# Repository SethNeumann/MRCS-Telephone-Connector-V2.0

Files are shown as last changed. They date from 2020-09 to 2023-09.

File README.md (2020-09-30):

# REPO NAME: MRCS0Telephone-Connector-V2.0
## License: Creative Commons Attribution-NonCommercial-ShareAlike

This board provides connectors to extend the MRCS power and phone bus (used by the EBF31A Battery Feed and ATSN Dispatcher/Operator Boards) to as many as 12 stations. Pads are provided for a bucking converter to develop 12VDC for buzzers, LEDs and Relay Latches. I’ve been developing a series of circuit boards to perform the various functions needed to build a layout phone system, but I never made a central board to distribute the phone line and auxiliary power. In the past I assumed the user would use either telephone style “66 blocks” or barrier strips to distribute these signals, but that has become a road block for some users, so this board, with its on board screw terminals puts the basic connections in one place. Features:

• Takes power from the 6-conductor modular telephone and +24V power bus (note to phone people: this is positive 24 to keep things simple for non-phone model railroaders) • Two 6 conductor Jacks are provided for daisy chaining the bus. Connectors are oriented with the locking tab up for easy connection and disconnection.

• Connector pads provide up to 12 connections on 0.100 centers for Tip, Ring, +12 and Ground. If you are assembling your own board and need less connections, you can use screw terminals (or your favorite 0.100 connector) with fewer positions

• Optional auxiliary 6 position screw terminal brings all lines on the bus out for easy access

• Polarity protection diode protects against use of non-reversing (DCC Bus 6 conductor cable)

- 2.1 mm barrel jack for 24vdc input

• Pads for an LM2596 bucking converter which provides 12V for buzzers, LEDs and Relay Latches etc., or you can substitute a boost converter for any voltage up to 35VDC

All components are through-hole technology for ease of assembly and repair.

You are free to download these files and make your own boards or cou can purchase bare boards or assembled and tested product from Model Railroad Control Systems.

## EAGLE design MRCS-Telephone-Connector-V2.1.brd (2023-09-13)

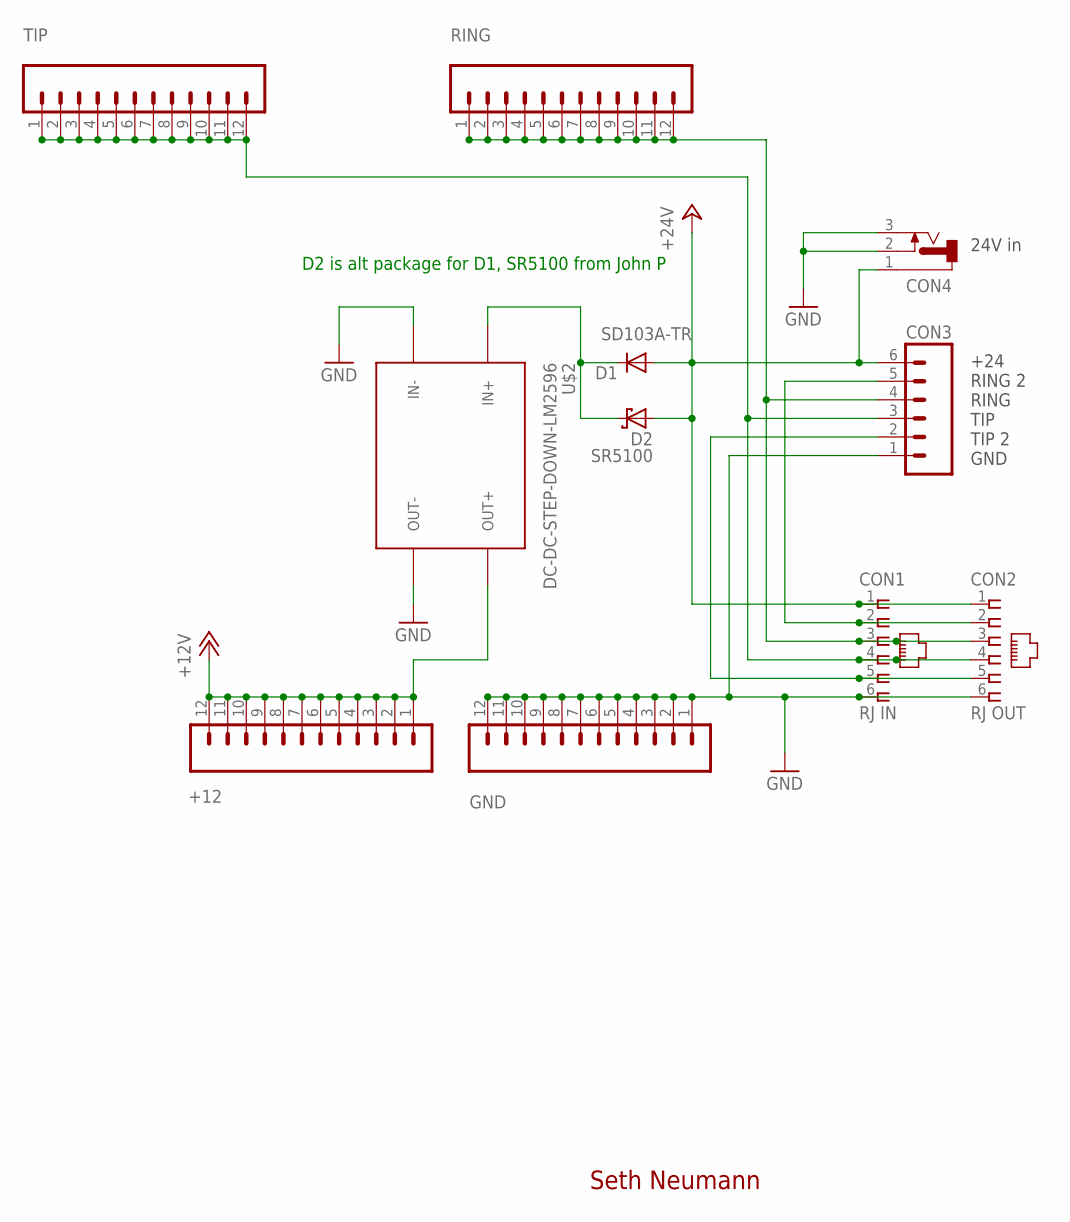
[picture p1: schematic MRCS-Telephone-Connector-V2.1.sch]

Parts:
+12: CONNECTOR-M12LOCK; 1X12_LOCK
CON1: RJ IN; RJ25-INVERTED
CON2: RJ OUT; RJ25-INVERTED
CON3: CONNECTOR-M06LOCK; 1X06_LOCK
CON4: CONNECTOR-DC-POWER-RA; DCJ0202
D1: SD103A-TR; DIODE-1N4001
D2: SR5100; AG
GND: CONNECTOR-M12LOCK; 1X12_LOCK
RING: CONNECTOR-M12LOCK; 1X12_LOCK
TIP: CONNECTOR-M12LOCK; 1X12_LOCK
U$2: DC-DC-STEP-DOWN-LM2596

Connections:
+12V: +12.1, +12.2, +12.3, +12.4, +12.5, +12.6, +12.7, +12.8, +12.9, +12.10, +12.11, +12.12, U$2.OUT+
+24V: CON1.1, CON2.1, CON3.6, CON4.1, D1.A, D2.A
GND: CON1.6, CON2.6, CON3.1, CON4.2, CON4.3, GND.1, GND.2, GND.3, GND.4, GND.5, GND.6, GND.7, GND.8, GND.9, GND.10, GND.11, GND.12, U$2.IN-, U$2.OUT-
unnamed: D1.C, D2.C, U$2.IN+
RING: CON1.3, CON2.3, CON3.4, RING.1, RING.2, RING.3, RING.4, RING.5, RING.6, RING.7, RING.8, RING.9, RING.10, RING.11, RING.12
RING2: CON1.2, CON2.2, CON3.5
TIP: CON1.4, CON2.4, CON3.3, TIP.1, TIP.2, TIP.3, TIP.4, TIP.5, TIP.6, TIP.7, TIP.8, TIP.9, TIP.10, TIP.11, TIP.12
TIP2: CON1.5, CON2.5, CON3.2

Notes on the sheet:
Seth Neumann
+24 RING 2 RING TIP TIP 2 GND
24V in
D2 is alt package for D1, SR5100 from John P

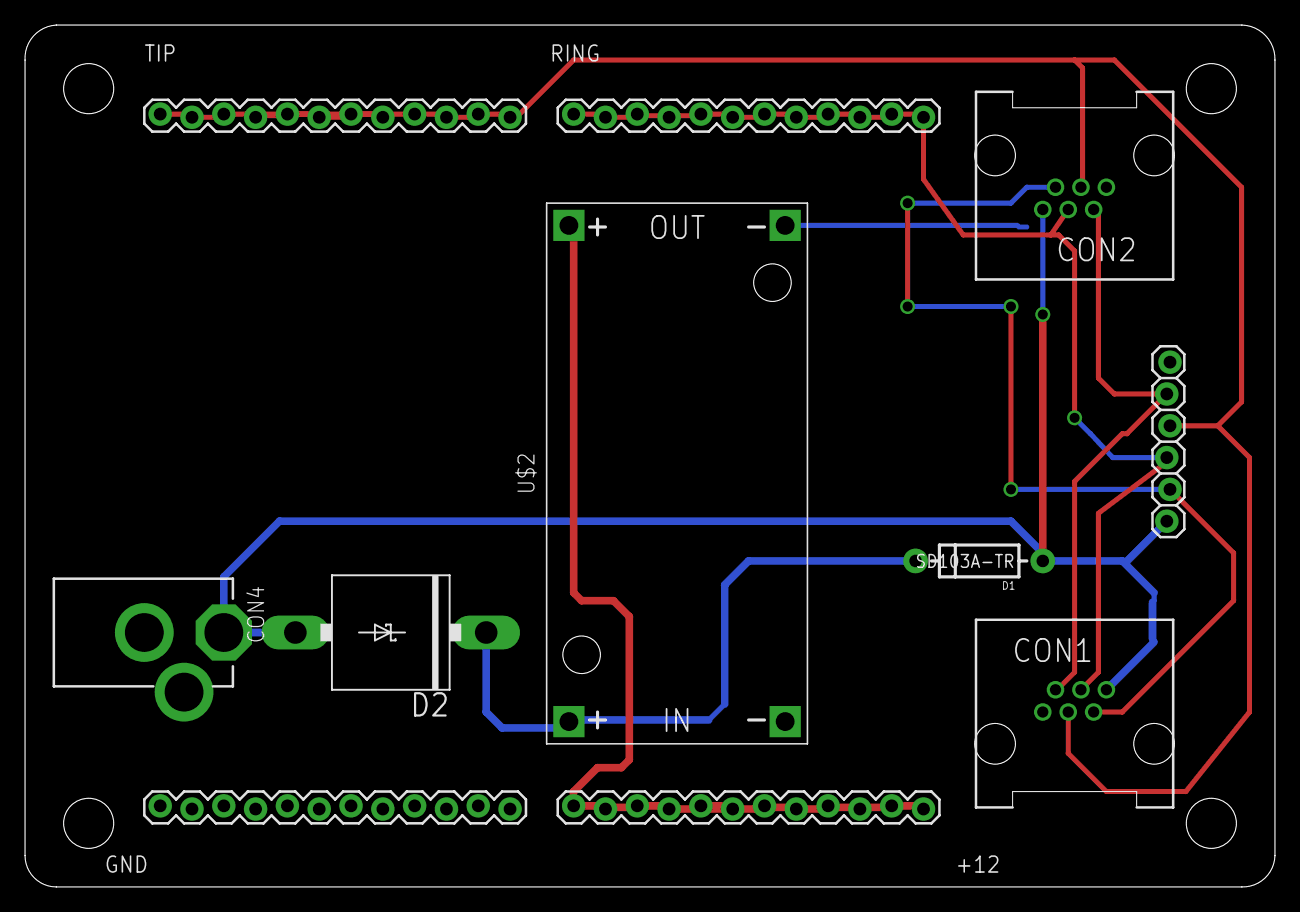
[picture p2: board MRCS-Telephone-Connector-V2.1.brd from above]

Board: 2 copper layers, 99.8 x 68.8 mm, 15 parts (0 on the bottom side), 8 nets.

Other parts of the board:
U$1: BOARD-DINRAIL-2.71IN-MRCS
U$4: MRCSLOGOTOP
U$5: MRCSLOGOBTM
U$6: CA-PROP65WARNING

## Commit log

2020-10-01 moved to GitHub
    [EagleTemplate-new.brd, EagleTemplate-new.sch, MRCS-Telephone-Connector-V2.0.brd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]
2020-12-20 change to single bucker
    change to single buckers
2023-09-13 changed to version 2.1
    added 5A schottkey diode
    [MRCS-Telephone-Connector-V2.1.brd, MRCS-Telephone-Connector-V2.1.sch]

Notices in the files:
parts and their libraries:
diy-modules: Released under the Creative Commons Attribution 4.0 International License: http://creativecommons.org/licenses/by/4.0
